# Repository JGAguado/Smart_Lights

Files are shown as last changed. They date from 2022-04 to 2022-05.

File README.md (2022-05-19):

[][releases]
[](LICENSE)

[][maintenance]
[][buymecoffee]

# Smart Lights X1
The Smart Lights X1 is an ESP32 based board for controlling a dimmeable 12V led strip. 

Note that the Maker Edition is designed with 1206 size SMD components, so it can be assembled manually.

<p float="left">
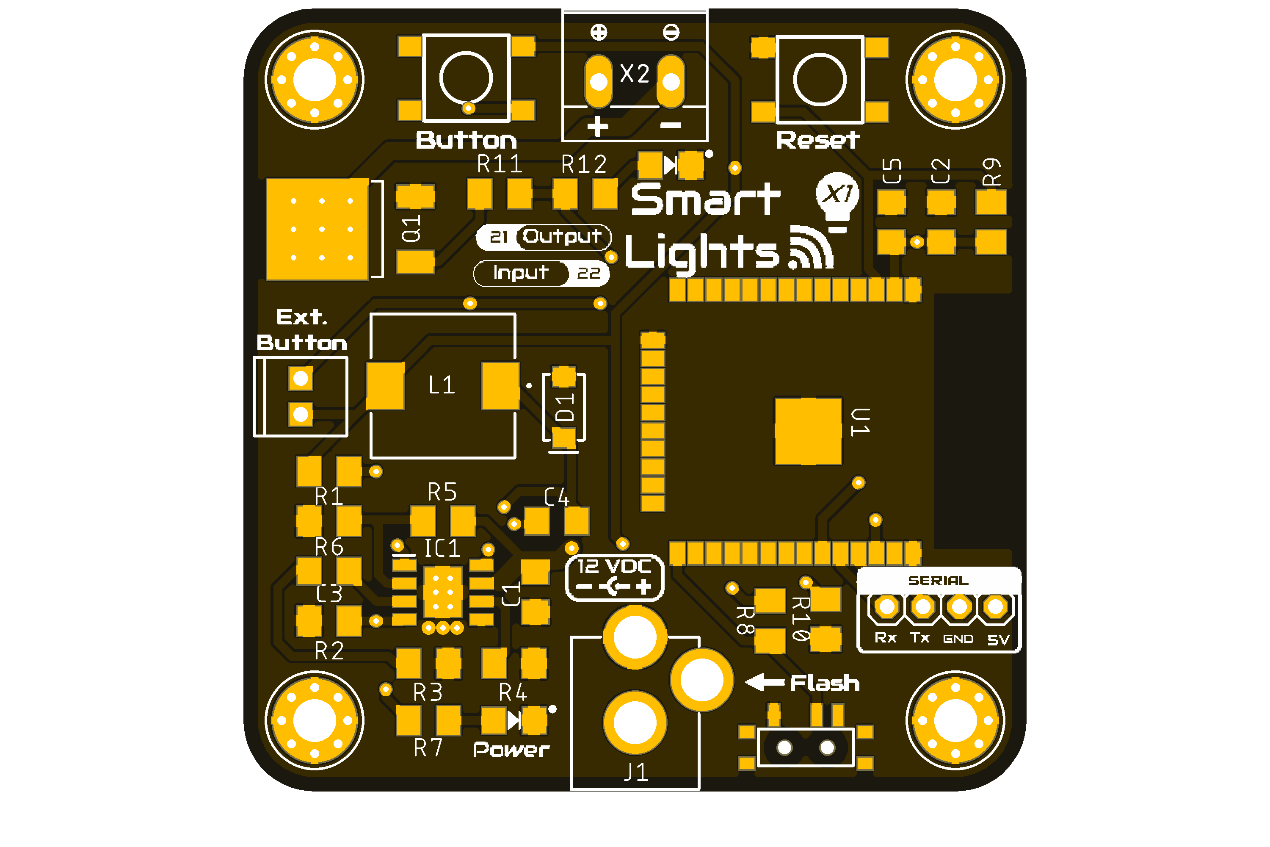
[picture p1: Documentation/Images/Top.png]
   
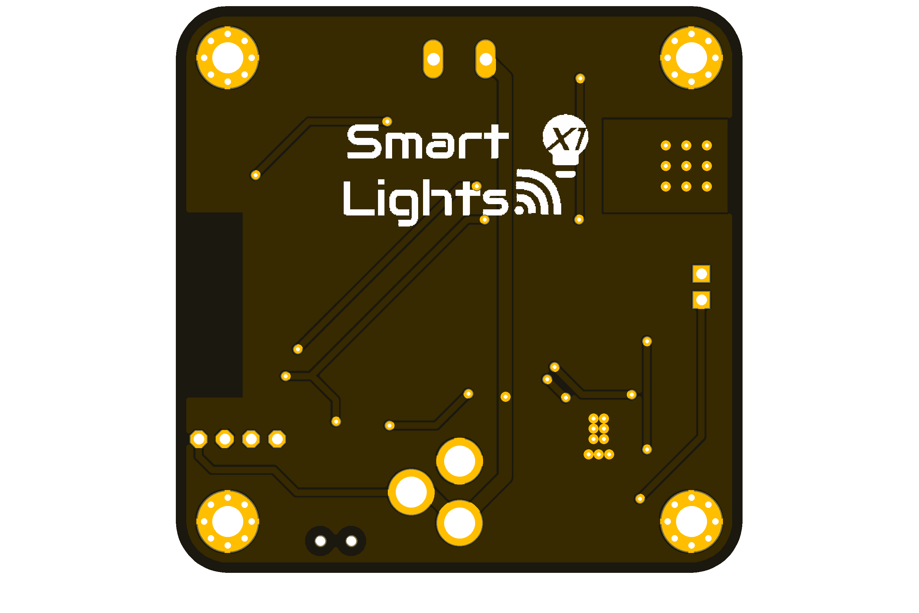
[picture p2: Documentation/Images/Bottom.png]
      
</p>

## Project tree

<li><a href="./Design/">Design</a></li>
<li><a href="./Documentation/">Documentation</a></li>

<li><a href="./README.md">README.md</a></li>

[releases-shield]: https://img.shields.io/github/release/JGAguado/Smart_Lights.svg?style=for-the-badge
[releases]: https://github.com/JGAguado/Smart_Lights/releases

[license-shield]: https://img.shields.io/badge/License-CC%20BY--NC--SA%204.0-lightgrey.svg?style=for-the-badge

[maintenance-shield]: https://img.shields.io/badge/maintainer-J.%20G.%20Aguado-blue.svg?style=for-the-badge
[maintenance]: https://github.com/JGAguado

[buymecoffee-shield]: https://img.shields.io/badge/buy%20me%20a%20coffee-support-yellow.svg?style=for-the-badge&logo=buymeacoffee
[buymecoffee]: https://www.buymeacoffee.com/J.G.Aguado

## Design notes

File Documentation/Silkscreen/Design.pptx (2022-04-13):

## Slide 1

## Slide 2

+

+

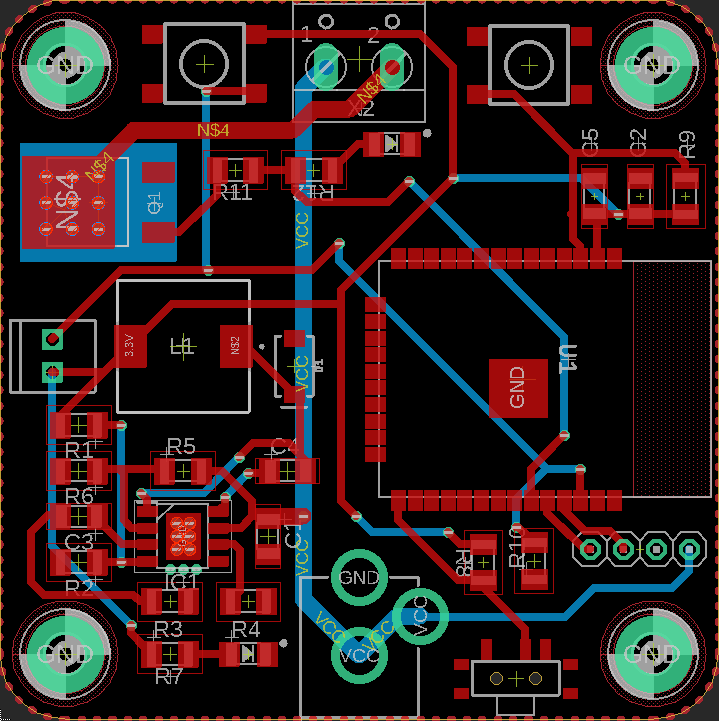
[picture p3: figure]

Button

Reset

X1

Smart Lights

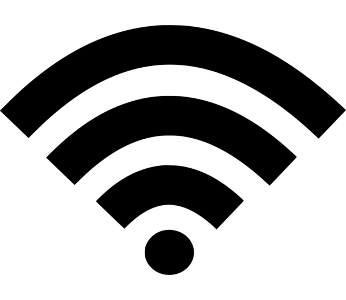
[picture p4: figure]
Internet and WiFi - Bibliothèques de Martigues

Output

21

Input

22

Ext.
Button

12 VDC

+

SERIAL

Rx

Tx

GND

5V

Flash

Power

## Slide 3

+

+

Button

Reset

Smart Lights

X1

Output

21

Input

22

Ext.
Button

12 VDC

+

SERIAL

Rx

Tx

GND

5V

Flash

Power

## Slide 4

Smart Lights

X1

Maker Edition

Maker:

Date:

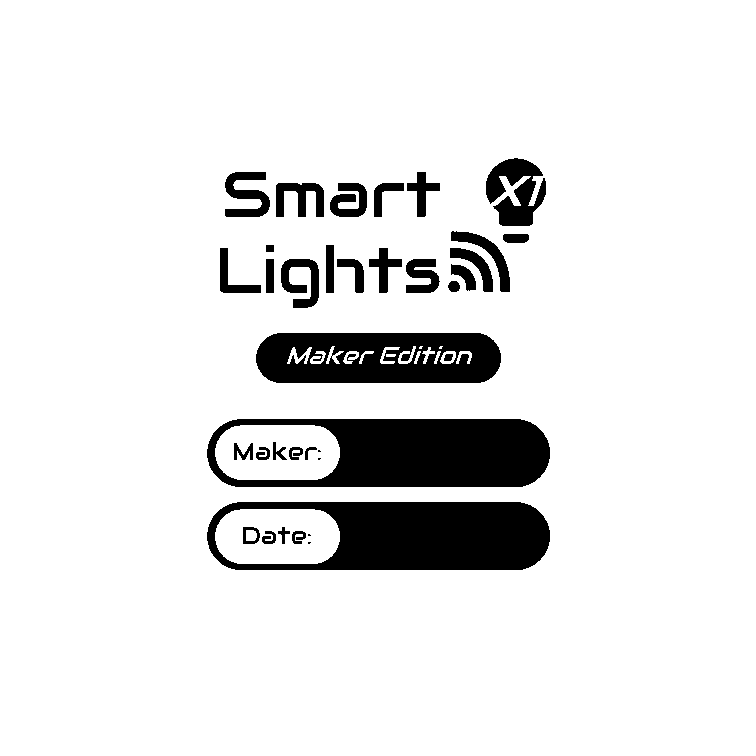
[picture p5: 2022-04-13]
Documentation/Silkscreen/Bottom.bmp

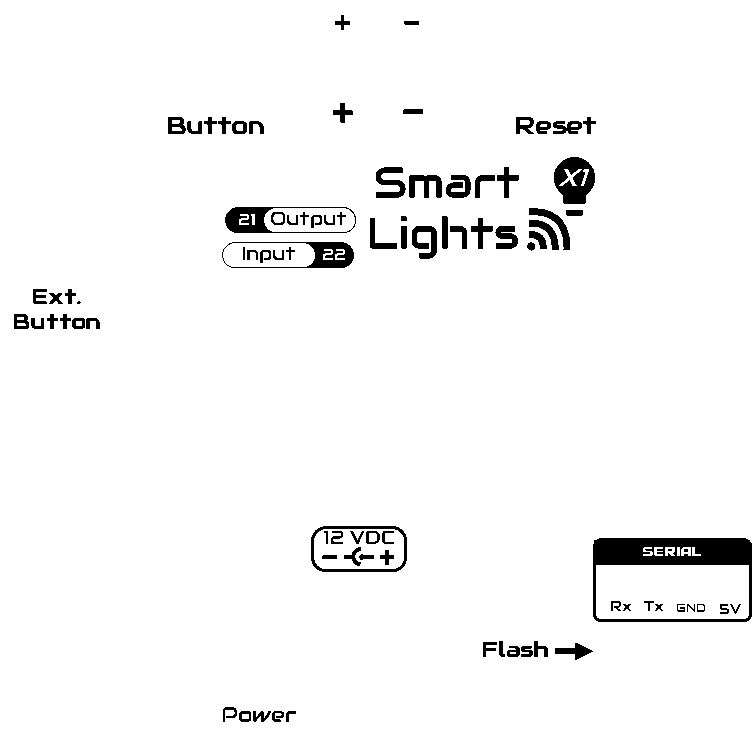
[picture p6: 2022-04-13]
Documentation/Silkscreen/Top.bmp

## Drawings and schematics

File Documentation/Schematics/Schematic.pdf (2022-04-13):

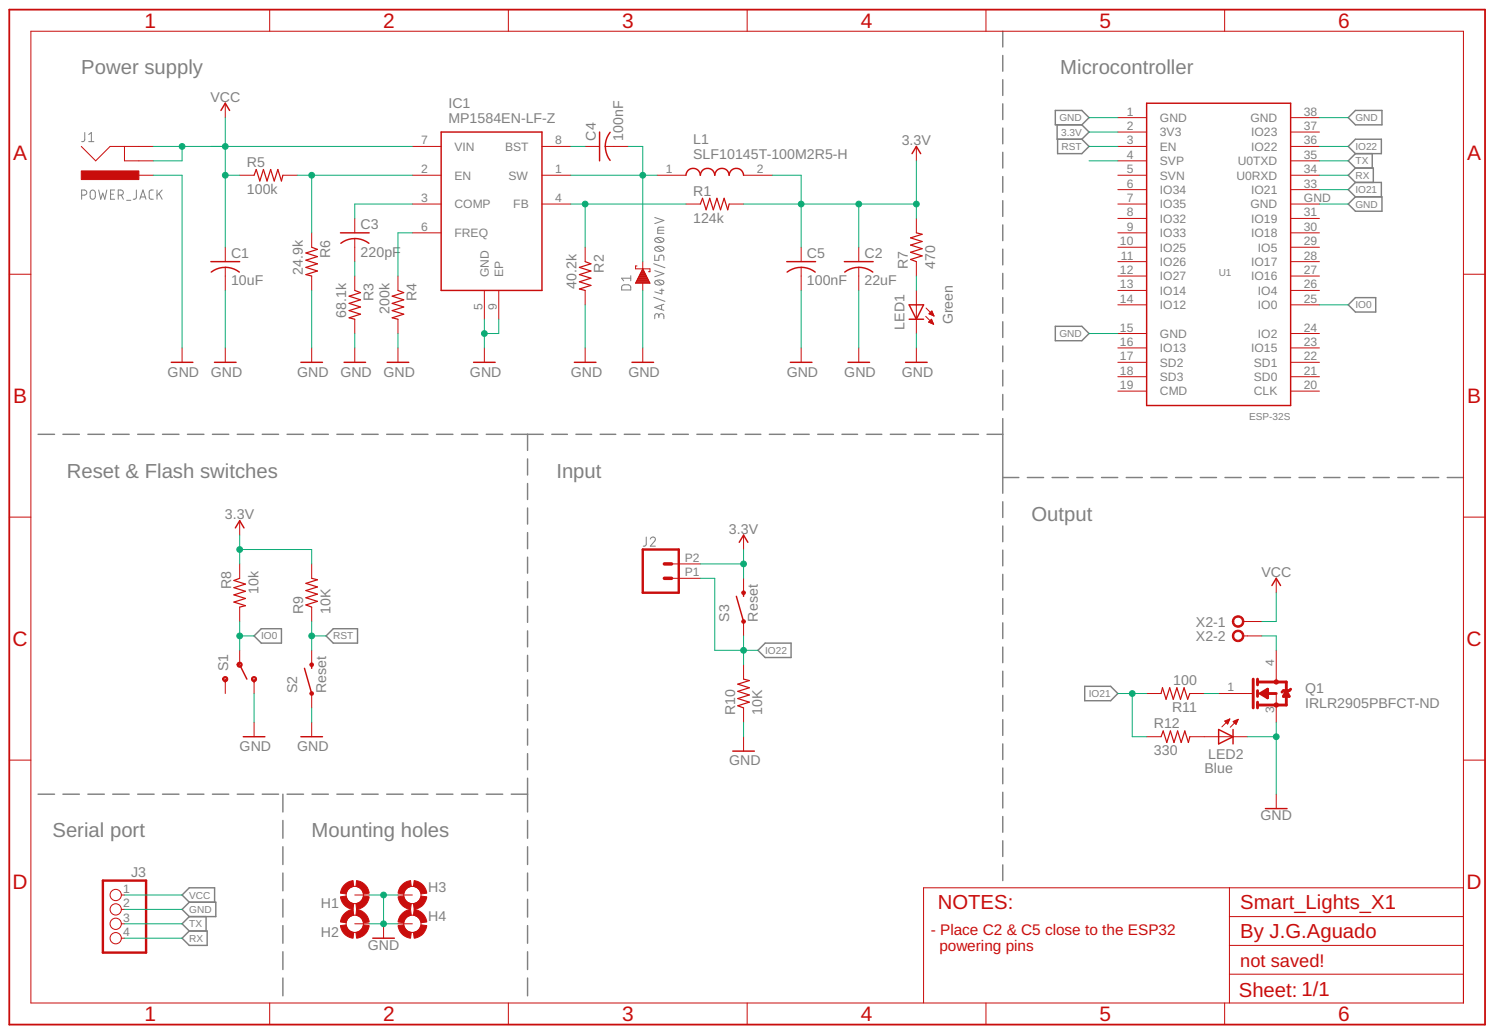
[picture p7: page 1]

VCC

- Place C2 & C5 close to the ESP32

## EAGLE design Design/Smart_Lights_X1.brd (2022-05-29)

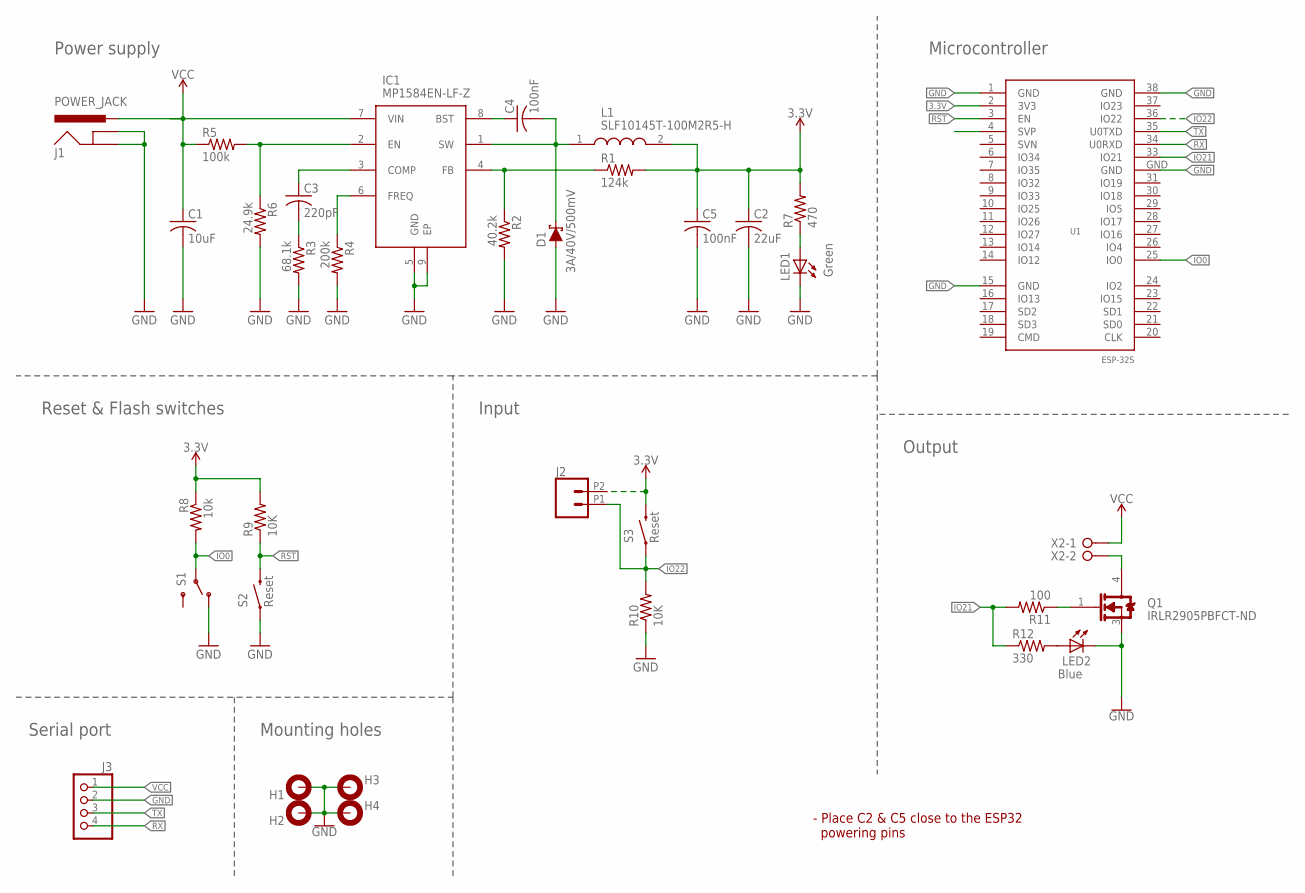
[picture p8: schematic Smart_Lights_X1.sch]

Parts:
C1: 10uF; C1206
C2: 22uF; C1206
C3: 220pF; C1206
C4, C5: 100nF; C1206
D1: 3A/40V/500mV; SMA-DIODE
H1, H2, H3, H4: MOUNT-PAD-ROUND; 3,0-PAD
IC1: MP1584EN-LF-Z; SOIC127P600X170-9N
J1: POWER_JACK; POWER_JACK_PTH
J2: CONN_022.54MM_SCREWTERM; 1X02_2.54_SCREWTERM
J3: PINHD-1X4; 1X04
L1: SLF10145T-100M2R5-H; SLF10145
LED1: Green; LED1206
LED2: Blue; LED1206
Q1: IRLR2905TRPBF; INFINEON_TECHNOLOGIES_IRLR2905TRPBF_0
R1: 124k; M1206
R2: 40.2k; M1206
R3: 68.1k; M1206
R4: 200k; M1206
R5: 100k; M1206
R6: 24.9k; M1206
R7: 470; M1206
R8: 10k; M1206
R9, R10: 10K; M1206
R11: 100; M1206
R12: 330; M1206
S1: SWITCH_SPDT; KPS-1290
S2, S3: Reset; TACTILE_SWITCH_TALL
U1: ESP-32S
X2: W237-02P; W237-132

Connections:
3.3V: C2.1, C5.1, J2.P2 (2), L1.2, R1.2, R7.2, R8.1, R9.2, S3.B2 (2), U1.2 (3V3)
GND: C1.2, C2.2, C5.2, D1.A, H1.B3,0, H1.P$2, H1.P$3, H1.P$4, H1.P$5, H1.P$6, H1.P$7, H1.P$8, H1.P$9, H2.B3,0, H2.P$2, H2.P$3, H2.P$4, H2.P$5, H2.P$6, H2.P$7, H2.P$8, H2.P$9, H3.B3,0, H3.P$2, H3.P$3, H3.P$4, H3.P$5, H3.P$6, H3.P$7, H3.P$8, H3.P$9, H4.B3,0, H4.P$2, H4.P$3, H4.P$4, H4.P$5, H4.P$6, H4.P$7, H4.P$8, H4.P$9, IC1.5 (GND), IC1.9 (EP), J1.GND, J1.GNDBREAK, J3.2, LED1.C, LED2.C, Q1.3 (SOURCE), R2.2, R3.2, R4.2, R6.2, R10.1, S1.O, S2.A2 (1), U1.1 (GND), U1.15 (GND), U1.38 (GND), U1.GND
IN_5: U1.4 (SVP)
IO0: R8.2, S1.P, U1.25 (IO0)
IO21: R11.2, R12.1, U1.33 (IO21)
IO22: J2.P1 (1), R10.2, S3.A2 (1), U1.36 (IO22)
unnamed: C4.1, IC1.8 (BST)
unnamed: C4.2, D1.C, IC1.1 (SW), L1.1
unnamed: Q1.4 (DRAIN), X2.2
unnamed: Q1.1 (GATE), R11.1
unnamed: IC1.4 (FB), R1.1, R2.1
unnamed: C3.2, R3.1
unnamed: C3.1, IC1.3 (COMP)
unnamed: IC1.6 (FREQ), R4.1
unnamed: IC1.2 (EN), R5.2, R6.1
unnamed: LED1.A, R7.1
unnamed: LED2.A, R12.2
RST: R9.1, S2.B2 (2), U1.3 (EN)
RX: J3.4, U1.34 (U0RXD)
TX: J3.3, U1.35 (U0TXD)
VCC: C1.1, IC1.7 (VIN), J1.PWR, J3.1, R5.1, X2.1

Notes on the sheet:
Reset & Flash switches
- Place C2 & C5 close to the ESP32 powering pins
Input
Output
Serial port
Mounting holes
Microcontroller
Power supply

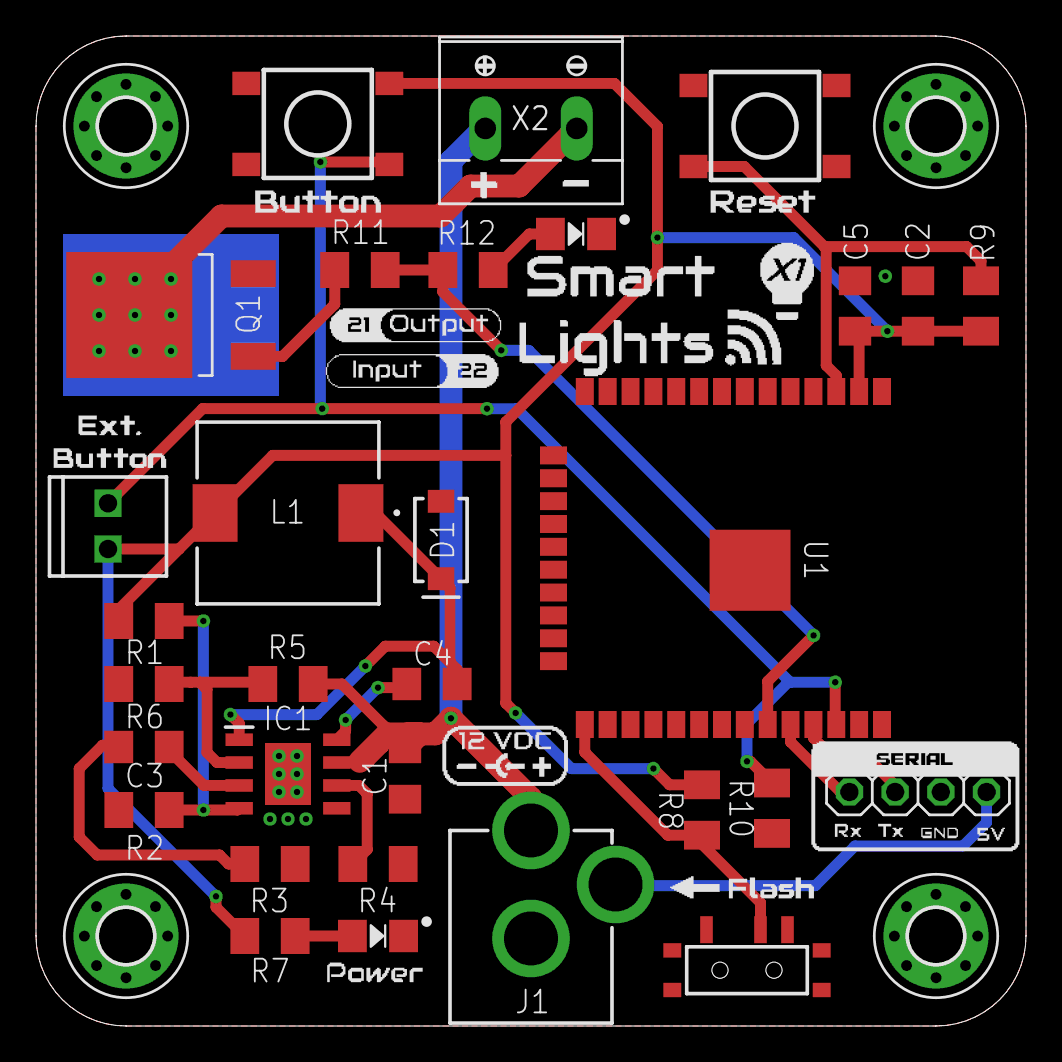
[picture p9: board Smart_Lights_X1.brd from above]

Board: 2 copper layers, 55.0 x 55.0 mm, 35 parts (0 on the bottom side), 20 nets.

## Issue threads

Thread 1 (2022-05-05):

Jack connector

JGAguado, 2022-05-05:
Fix the polarity definition

JGAguado, 2022-05-23:
Fixed on X4: 870e5f2d528101eb4a7c0e8587aa334a7bd36466

JGAguado, 2022-05-23:
Fixed on X1: 4ef9e64e1e64eb24f6314fec945d7e8ac022d3d5

Closed 2022-05-23.

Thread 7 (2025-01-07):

Getting error while calling thingspeak library

Ajju-lab, 2025-01-07:
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
I get this error how to solve this ?????

JGAguado, 2025-01-07:
Dear @Ajju-lab, I'm afraid I cannot help you with topic. However, and since it's more a generic thing of Thingspeak rather than my hardware I'd recommend you to open an issue directly on their repo (https://github.com/mathworks/thingspeak-arduino)

Closed 2025-01-07.

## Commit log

2022-04-13 Added silkscreen design
2022-04-13 Added design files
    [Smart_Lights_X1.brd, Smart_Lights_X1.sch]
2022-04-24 Updated silkscreen
    [Smart_Lights_X1.brd]
2022-05-23 Fixed DC Jack connection
    [Smart_Lights_X1.brd, Smart_Lights_X1.sch]
2022-05-29 C2 & C5 Grounded
    [Smart_Lights_X1.brd]

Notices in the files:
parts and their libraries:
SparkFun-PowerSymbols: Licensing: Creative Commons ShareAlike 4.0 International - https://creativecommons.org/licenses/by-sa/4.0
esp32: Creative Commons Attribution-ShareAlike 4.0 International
